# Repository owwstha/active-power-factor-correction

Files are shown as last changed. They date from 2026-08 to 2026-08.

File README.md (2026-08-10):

## active power factor correction

### Overview & Objectives

The primary objective was to design a high-efficiency Active Power Factor Correction stage. Utilizing a PI control loop to modulate PWM signals, the system achieves a Power Factor (PF) > 0.99. Key design priorities included:
* Minimizing THD.
* Regulating the DC bus voltage against AC input fluctuations and sudden load transients.

---

### Technical Details

* **Control Architecture**: A dual-loop PI control system manages the feedback: a outer voltage PI loop stabilizes the DC bus output, while a fast inner current PI loop continuously adjusts the duty cycle of the PWM signal.
* **Power Stage**: A diode bridge rectifier converts the AC line voltage to unsmoothed DC, which is immediately fed into a high-frequency Boost Converter. The switched PWM controls the boost stage to shape the input current into a pure sinusoidal waveform aligned with the AC voltage.

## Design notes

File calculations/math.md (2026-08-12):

### Mathematical Formulation & Control Design

#### 1. Inductor Current Ripple ($\Delta I_L$)
The worst-case inductor current ripple occurs at a 50% duty cycle ($D = 0.5$):

$$\Delta I_L = \frac{V_o \cdot D \cdot (1 - D)}{L \cdot f_s}$$

Substituting $V_o = 20\text{V}$, $L = 470\mu\text{H}$, and $f_s = 50\text{kHz}$:

$$\Delta I_L = \frac{20\text{V} \times 0.5 \times 0.5}{470\mu\text{H} \times 50\text{kHz}} \approx 0.213\text{A} \quad (213\text{mA})$$

---

#### 2. Output Capacitor Voltage Ripple ($\Delta V_o$)
In single-phase APFC, double-line frequency ($2 f_{\text{line}} = 100\text{Hz}$) causes peak-to-peak voltage ripple on the DC bus:

$$\Delta V_{o,\text{p-p}} = \frac{I_o}{2 \pi f_{\text{line}} \cdot C} = \frac{P_{\text{out}}}{2 \pi f_{\text{line}} \cdot C \cdot V_o}$$

For a nominal load current $I_o \approx 0.6\text{A}$ at $f_{\text{line}} = 50\text{Hz}$ and $C = 1000\mu\text{F}$:

$$\Delta V_{o,\text{p-p}} = \frac{0.6\text{A}}{2 \pi \times 50\text{Hz} \times 1000\mu\text{F}} \approx 1.91\text{V}_{\text{p-p}}$$

---

#### 3. PI Controller Gains

* **Inner Loop (Current Control)**
  * P=1, I=50
  * Fast control loop designed to force inductor current $I_L(t)$ to track the rectified AC voltage reference.
  * **$K_{p,i}$**: High proportional gain to maximize bandwidth and minimize switching ripple phase error.
  * **$K_{i,i}$**: Integral gain to eliminate steady-state current tracking error.

* **Outer Loop (Voltage Control)**
  * P=0.1, I=10
  * Slow control loop regulating the average output DC voltage ($20\text{V}$).
  * **$K_{p,v}$**: Proportional gain tuned for low crossover frequency ($<20\text{Hz}$) to avoid amplifying $100\text{Hz}$ ripple into the current reference.
  * **$K_{i,v}$**: Integral gain ensuring zero steady-state error under varying load conditions.

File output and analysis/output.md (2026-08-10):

### System Specifications

| Parameter | Value / Component |
| :--- | :--- |
| **Input Voltage** | $9\text{V AC RMS}$ ($\approx 12.7\text{V}_{\text{peak}}$) |
| **Output Voltage** | $20\text{V DC}$ (Regulated) |
| **Switching Frequency** | $50\text{kHz}$ |
| **Boost Inductor** | $470\mu\text{H}$ |
| **Output Capacitor** | $1000\mu\text{F}$ |
| **Rectifier / Boost Diode** | 1N5819 (Schottky) / UF4004 (Ultra-Fast) |

---

### Simulation Output

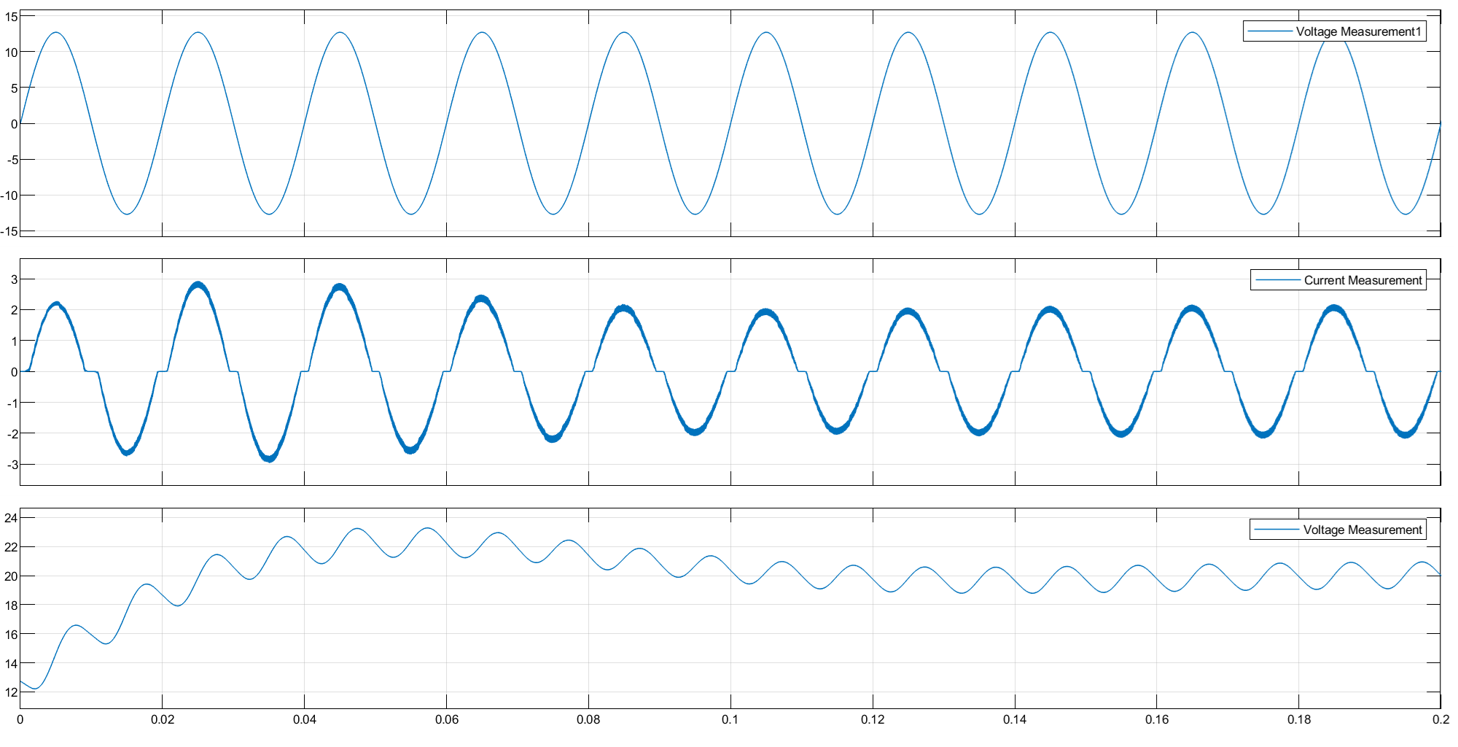
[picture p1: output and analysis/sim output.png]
APFC Simulation Waveforms


---

### Simulation Waveforms & Analysis

#### 1. Input Voltage & Current Waveforms (Grid Side)
* **Phase Synchronization**: The input AC current tracks the sinusoidal input AC voltage in phase, confirming low phase shift and high Power Factor ($\text{PF} \approx 1$).
* **Current Shaping & Distortion**: The current loop shapes the waveform into a sinusoid. Small zero-crossing dead zones are observed during polarity switching due to bridge rectifier diode forward voltage drops.
* **Switching Ripple**: High-frequency current ripple is visible along the sinusoidal envelope as a result of the $50\text{kHz}$ switching action across the $470\mu\text{H}$ boost inductor.

#### 2. Output DC Voltage Response
* **Steady-State Regulation**: The outer PI loop maintains a continuous average DC level of $20\text{V}$.
* **Output Ripple**: A $100\text{Hz}$ low-frequency ripple ($\sim 2\text{V}_{\text{p-p}}$) is present, caused by double-line frequency power fluctuations standard in single-phase PFC systems, buffered by the $1000\mu\text{F}$ capacitor.

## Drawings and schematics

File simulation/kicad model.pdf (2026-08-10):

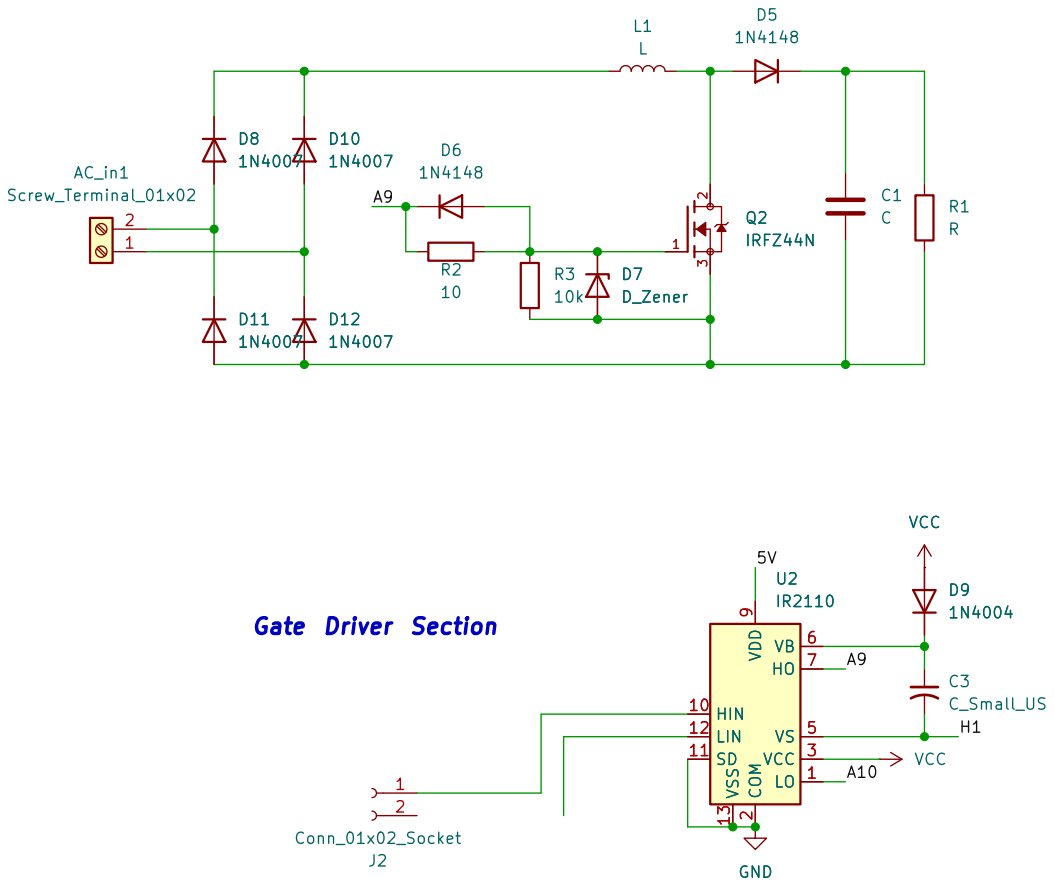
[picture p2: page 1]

Size: A4 | Rev:
KiCad E.D.A. 10.0.3 | Id: 1/1

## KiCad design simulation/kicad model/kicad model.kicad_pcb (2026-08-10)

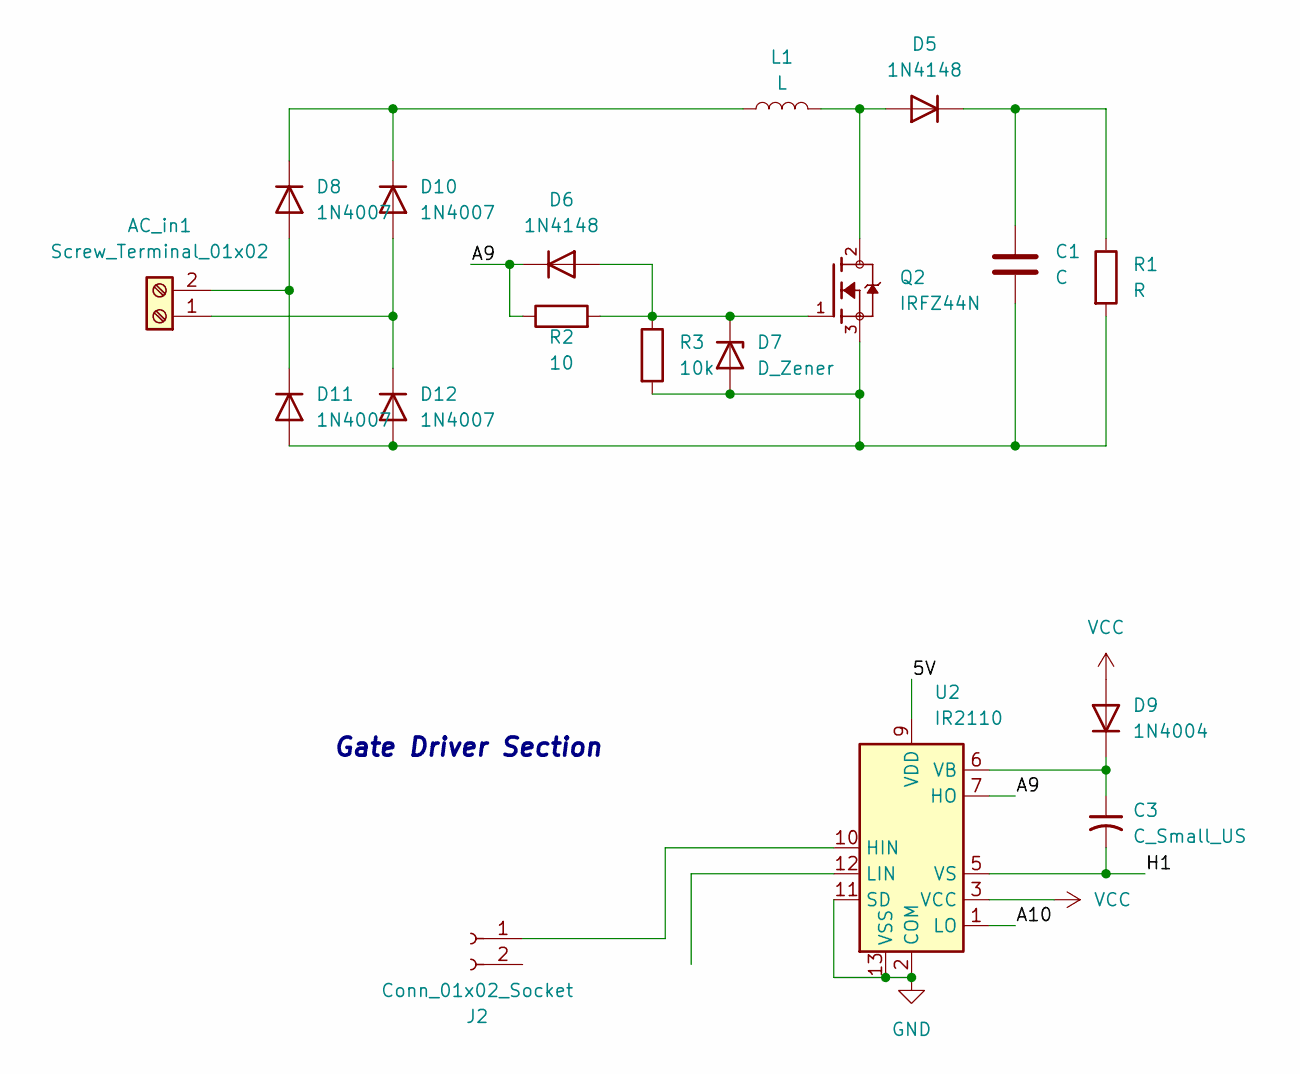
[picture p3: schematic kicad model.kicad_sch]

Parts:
AC_in1: Screw_Terminal_01x02; TerminalBlock_Xinya_XY308-2.54-2P_1x02_P2.54mm_Horizontal
C1: C; C_Radial_D6.3mm_H5.0mm_P2.50mm
C3: C_Small_US; C_Radial_D6.3mm_H7.0mm_P2.50mm
D5, D6: 1N4148; D_DO-35_SOD27_P7.62mm_Horizontal
D7: D_Zener; D_A-405_P7.62mm_Horizontal
D8, D10, D11, D12: 1N4007; D_DO-41_SOD81_P10.16mm_Horizontal
D9: 1N4004; D_A-405_P7.62mm_Horizontal
J2: Conn_01x02_Socket; PinHeader_1x01_P2.54mm_Vertical
L1: L; L_Axial_L5.3mm_D2.2mm_P10.16mm_Horizontal_Vishay_IM-1
Q2: IRFZ44N; TO-247-3_Vertical; PARTREV 09/21/10
R1: R; R_Axial_DIN0207_L6.3mm_D2.5mm_P10.16mm_Horizontal
R2: 10; R_Axial_DIN0207_L6.3mm_D2.5mm_P7.62mm_Horizontal
R3: 10k; R_Axial_DIN0207_L6.3mm_D2.5mm_P7.62mm_Horizontal
U2: IR2110; DIP-14_W7.62mm

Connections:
/5V: U2.9 (VDD)
/A9: D6.1 (K), R2.1, U2.7 (HO)
/A10: U2.1 (LO)
/H1: C3.2, U2.5 (VS)
GND: U2.2 (COM), U2.11 (SD), U2.13 (VSS)
unnamed: AC_in1.1, D10.2 (A), D12.1 (K)
unnamed: AC_in1.2, D8.2 (A), D11.1 (K)
unnamed: D5.2 (A), L1.2, Q2.2
unnamed: C1.1, D5.1 (K), R1.1
unnamed: D6.2 (A), D7.1 (K), Q2.1, R2.2, R3.1
unnamed: C3.1, D9.1 (K), U2.6 (VB)
unnamed: D8.1 (K), D10.1 (K), L1.1
unnamed: C1.2, D7.2 (A), D11.2 (A), D12.2 (A), Q2.3, R1.2, R3.2
unnamed: J2.1 (Pin_1_1), U2.10 (HIN)
VCC: D9.2 (A), U2.3 (VCC)

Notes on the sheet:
Gate Driver Section

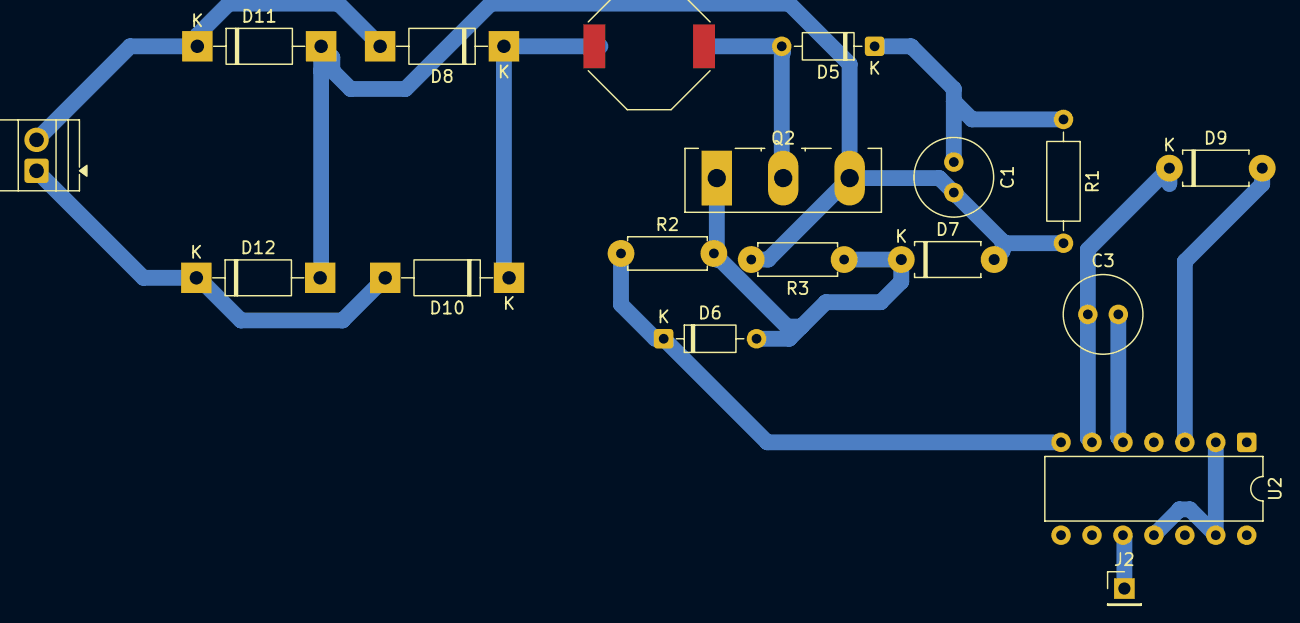
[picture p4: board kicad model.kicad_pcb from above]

Board: 2 copper layers, 18 parts (0 on the bottom side), 13 nets.
